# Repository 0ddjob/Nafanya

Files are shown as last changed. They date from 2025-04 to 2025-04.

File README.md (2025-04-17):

# Нафаня (Nafanya) ZX Spectrum Clone
The Нафаня is a late Soviet-era (1991) ZX Spectrum clone out of the Russian SFSR.<br>  
My Нафаня is serial no. 00872.<br>

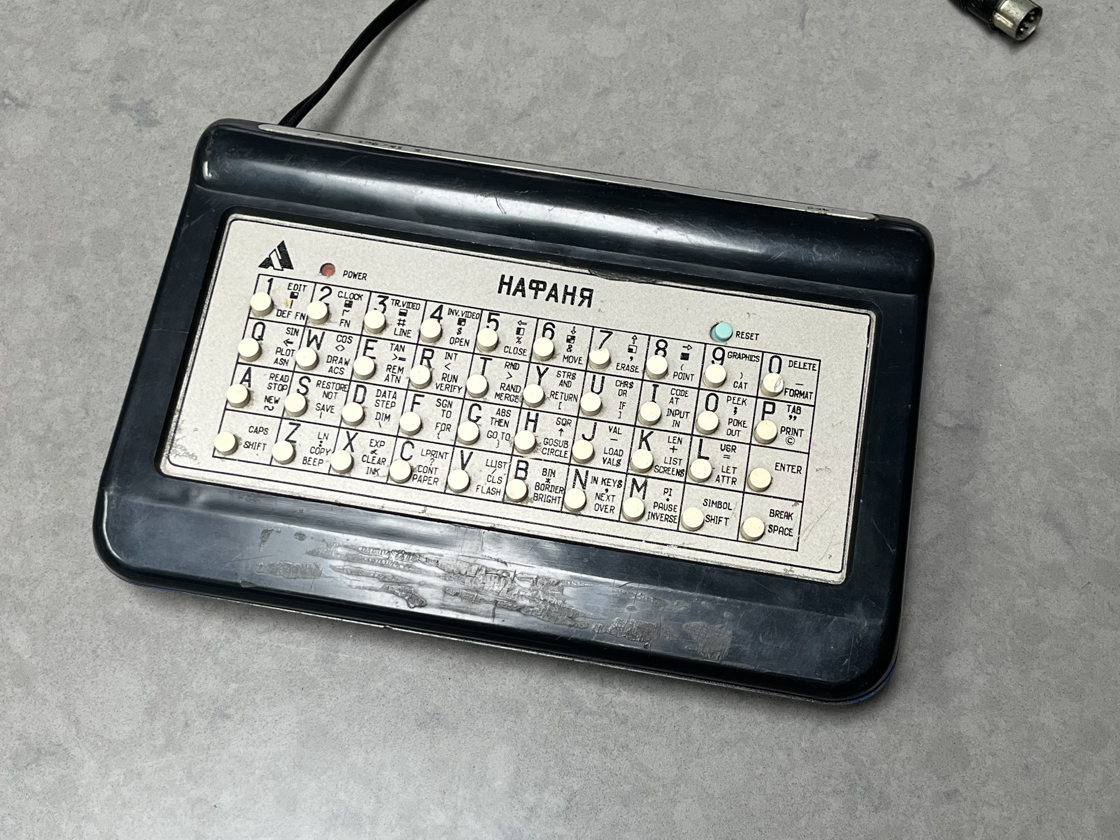
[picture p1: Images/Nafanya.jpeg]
Nafanya


My particular example has a nice, ceramic Z80 from DDR (East Germany) as well as a ceramic БМК (Basic Matrix Crystal, Soviet version of a ULA or Gate Array).<br>

It looked like the original, good quality capacitors were removed from my machine due to their precious-metal content.  They were substituted with poor quality replacements.  I, in turn, replaced them with better quality ones ... this greatly stabilised the RGB video output!  I also added a lot more decoupling capacitors - there was provision for them on the board but they were not installed.<br>

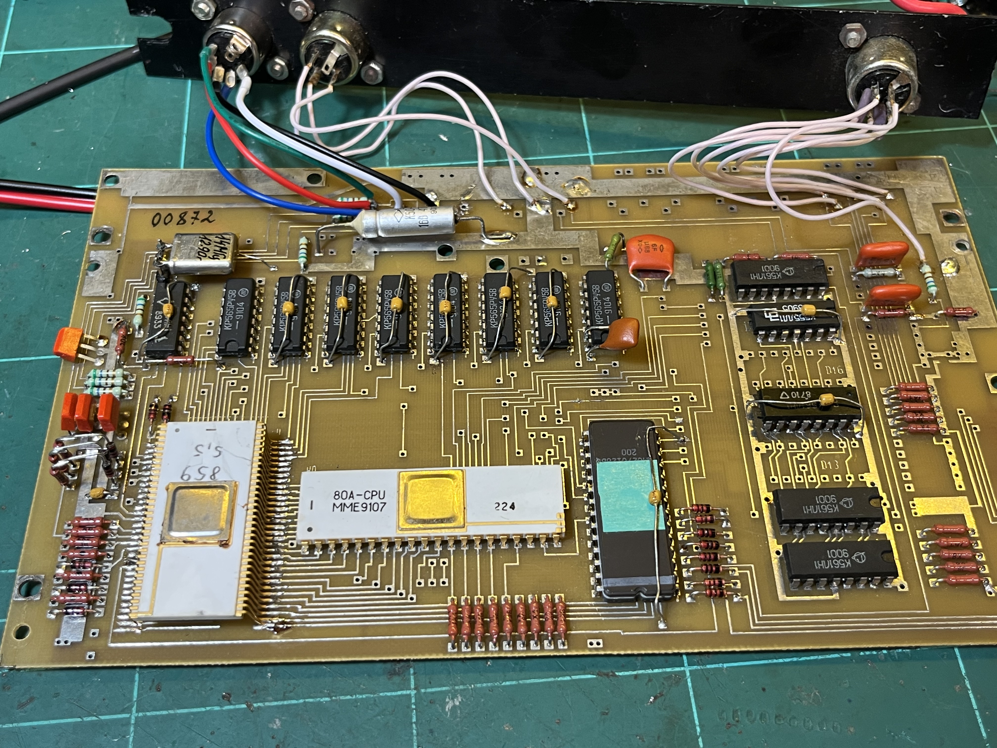
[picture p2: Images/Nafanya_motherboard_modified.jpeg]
Nafanya motherboard


## [Video](https://www.youtube.com/playlist?list=PL5pwokf56wMLiZ0rl97ZL9QdxtgF-uewT)
My YouTube videos:
- [Part 1 (Power On & Troubleshooting)](https://youtu.be/pPQIZv7UhS0)
- [Part 2 (Quick Update)](https://youtu.be/jH4AOVMjng8)
- [Part 3 (Replacement Keyboard Plans)](https://youtu.be/gZ2KwFe9IKs)

## [ROM](/ROM)
The ROM from my machine can be found in this repository.<br>

It has a pretty cool boot screen - I assume this is depicting the character "Нафаня" the computer is named after, a домовой (domovoy, or house spirit) from the Soviet animated film series "Домовёнок Кузя" (Domovyonok Kuzya, or "Kuzya the Little Domovoy") which is based on a children's book by Tatiana Aleksandrova.<br>

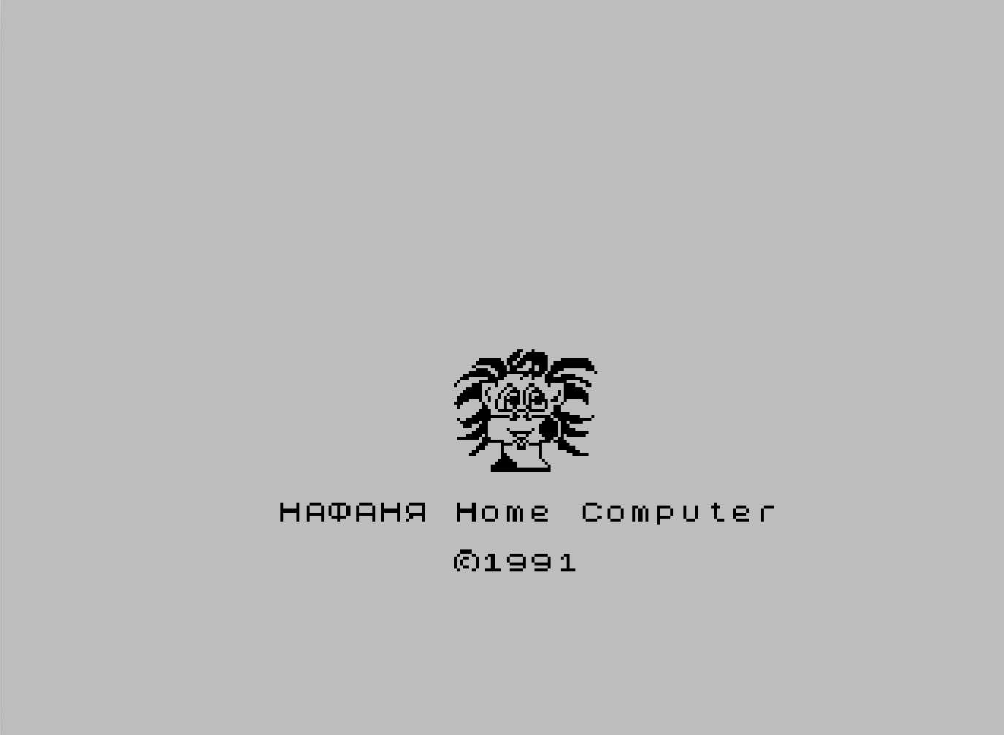
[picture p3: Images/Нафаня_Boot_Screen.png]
Nafanya boot screen


## [New Keyboard](/Nafanya_Keyboard)
The keyboard is not terribly good. Here is a re-designed one using tactile switches that should fit in the existing case.<br>

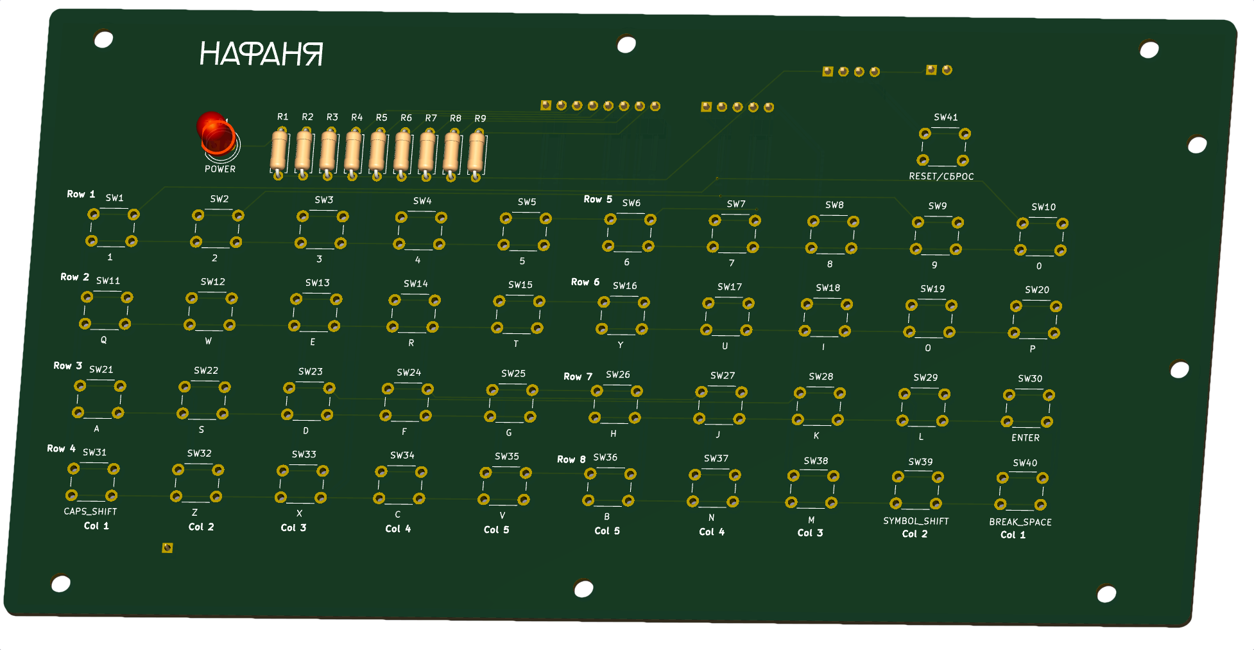
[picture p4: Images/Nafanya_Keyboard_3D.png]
Modern Nafanya Keyboard


### Status
6-Apr-2025:  Still being finalised. The switch positions are slightly off as you go from left to right.
17-Apr-2025: Finalised switch layout, sent for test fabrication.

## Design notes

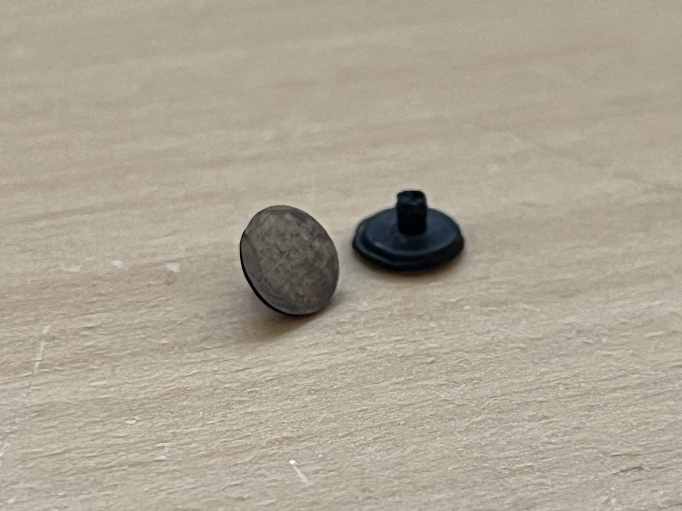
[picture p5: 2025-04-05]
Images/Nafanya_Keyboard_2.jpeg

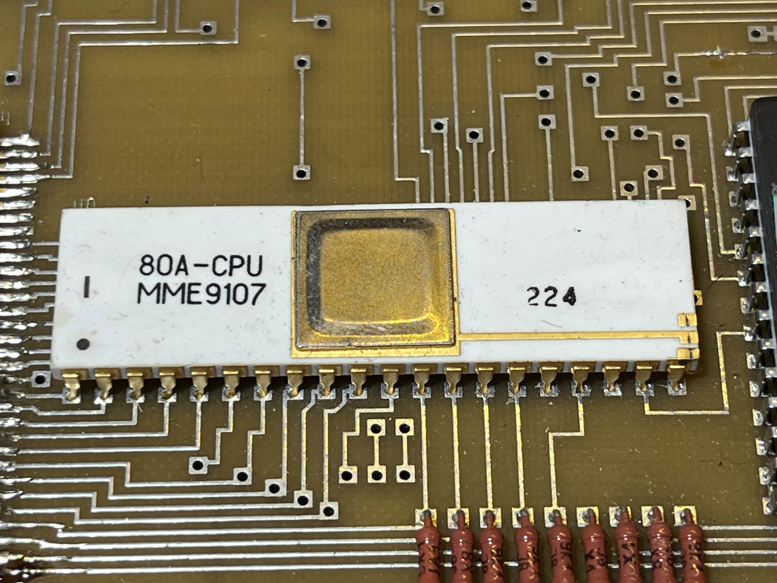
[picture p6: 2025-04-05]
Images/Nafanya_CPU_DDR_Z80.jpeg

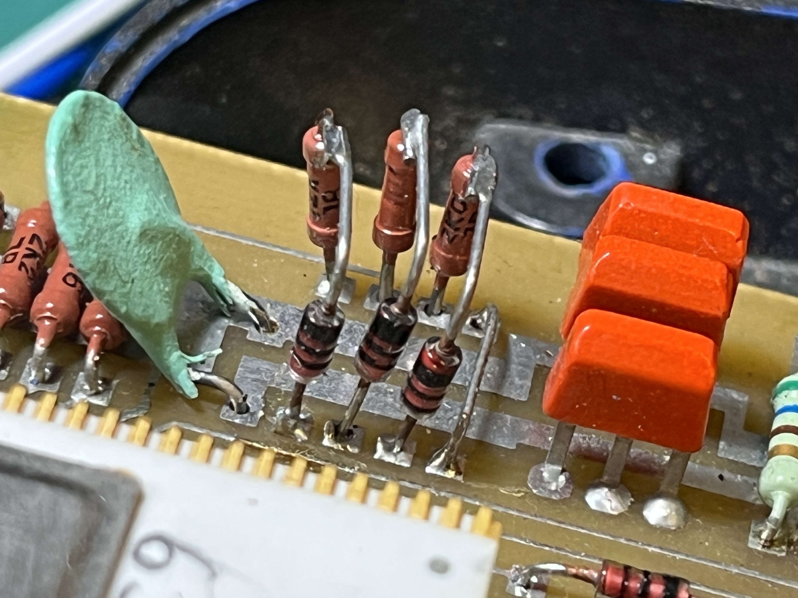
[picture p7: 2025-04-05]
Images/Nafanya_Video_circuit_4.jpeg

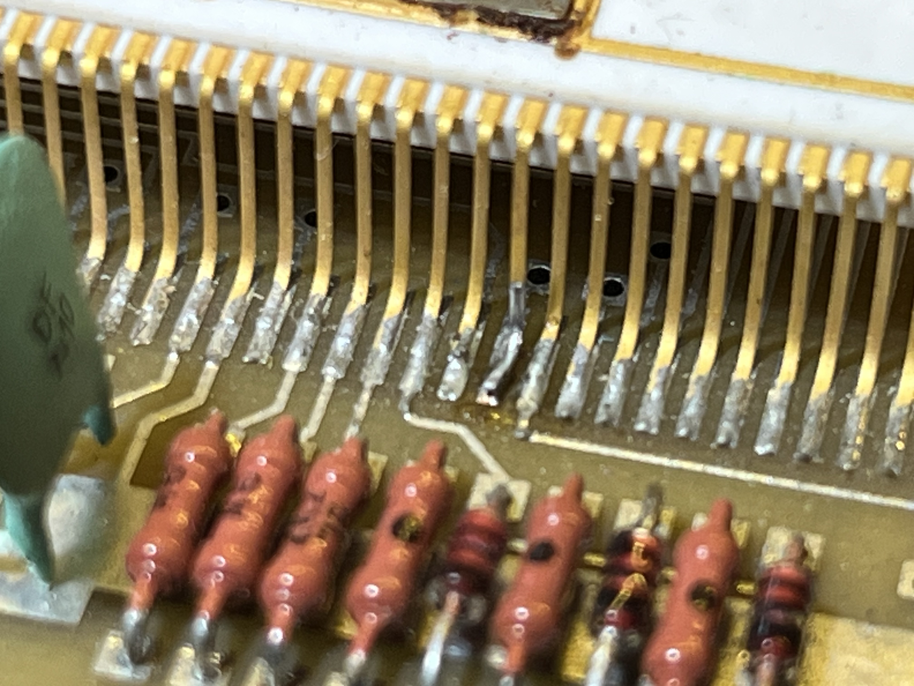
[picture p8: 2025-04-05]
Images/Nafanya_BMC_dodgy_leg.jpeg

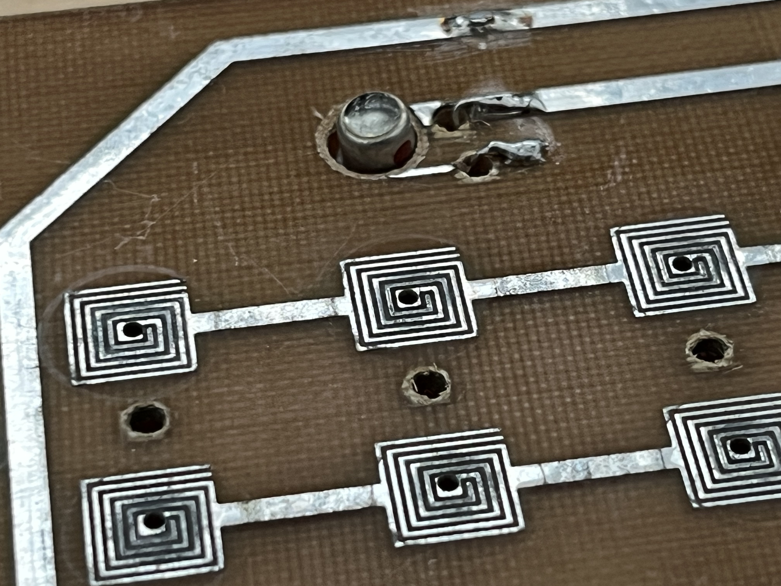
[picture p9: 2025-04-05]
Images/Nafanya_Keyboard_4.jpeg

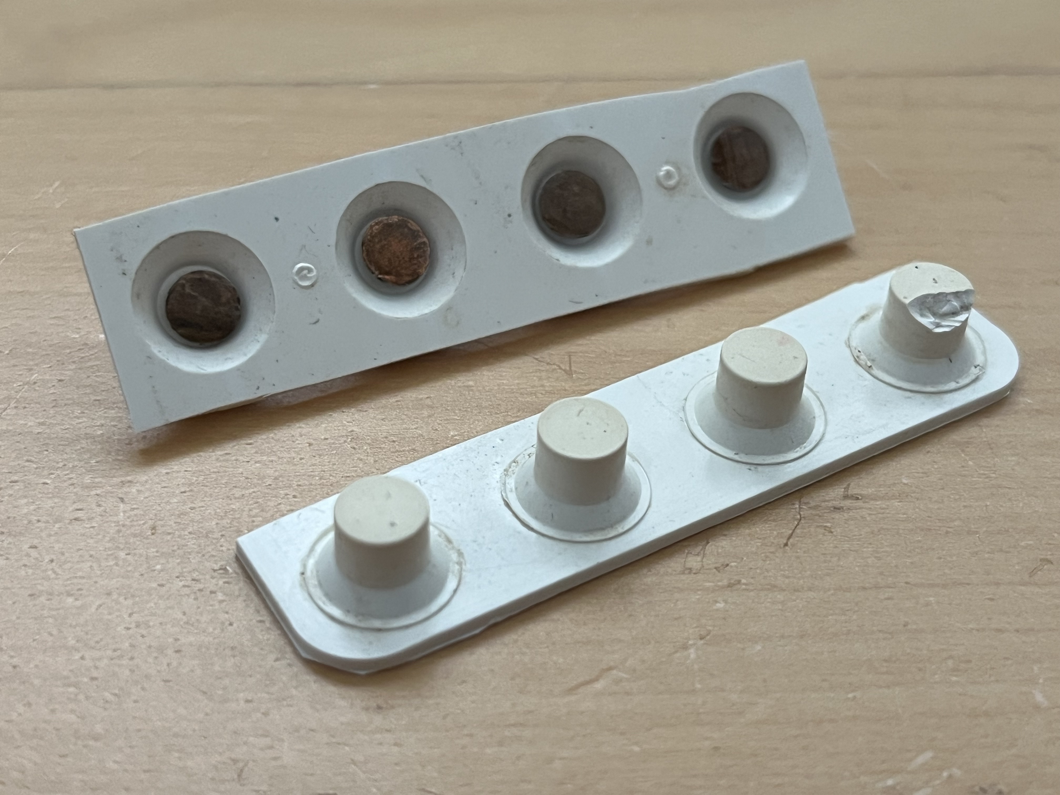
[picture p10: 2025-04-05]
Images/Nafanya_Keyboard_1.jpeg

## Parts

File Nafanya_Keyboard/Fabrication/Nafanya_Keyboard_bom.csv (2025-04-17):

Designator | Quantity | Value | Footprint | Package | MPN | DNP | Mount_Type | Description | Sim.Pins
D1 | 1 | POWER | LED_D5.0mm |  |  |  | tht | Light emitting diode | 1=K 2=A
J1 | 1 | Speaker/Reset/Power | PinHeader_1x04_P2.54mm_Horizontal |  |  |  | tht | Generic connector, single row, 01x04, script generated
J2 | 1 | Columns | PinHeader_1x05_P2.54mm_Horizontal |  |  |  | tht | Generic connector, single row, 01x05, script generated
J3 | 1 | Rows | PinHeader_1x08_P2.54mm_Horizontal |  |  |  | tht | Generic connector, single row, 01x08, script generated
J4 | 1 | Faceplate GND | PinSocket_1x01_P2.54mm_Vertical |  |  |  | tht | Generic connector, single row, 01x01, script generated
LS1 | 1 | Speaker | PinHeader_1x02_P2.54mm_Vertical |  |  |  | tht | Speaker
R1 | 1 | 300Ω | R_Axial_DIN0207_L6.3mm_D2.5mm_P7.62mm_Horizontal |  |  |  | tht | Resistor
R2, R3, R4, R5, R6, R7, R8, R9 | 8 | 10KΩ | R_Axial_DIN0207_L6.3mm_D2.5mm_P7.62mm_Horizontal |  |  |  | tht | Resistor
SW1 | 1 | 1 | SW_PUSH_6mm_H8.5mm |  |  |  | tht | Push button switch, normally open, two pins, 45° tilted
SW10 | 1 | 0 | SW_PUSH_6mm_H8.5mm |  |  |  | tht | Push button switch, normally open, two pins, 45° tilted
SW11 | 1 | Q | SW_PUSH_6mm_H8.5mm |  |  |  | tht | Push button switch, normally open, two pins, 45° tilted
SW12 | 1 | W | SW_PUSH_6mm_H8.5mm |  |  |  | tht | Push button switch, normally open, two pins, 45° tilted
SW13 | 1 | E | SW_PUSH_6mm_H8.5mm |  |  |  | tht | Push button switch, normally open, two pins, 45° tilted
SW14 | 1 | R | SW_PUSH_6mm_H8.5mm |  |  |  | tht | Push button switch, normally open, two pins, 45° tilted
SW15 | 1 | T | SW_PUSH_6mm_H8.5mm |  |  |  | tht | Push button switch, normally open, two pins, 45° tilted
SW16 | 1 | Y | SW_PUSH_6mm_H8.5mm |  |  |  | tht | Push button switch, normally open, two pins, 45° tilted
SW17 | 1 | U | SW_PUSH_6mm_H8.5mm |  |  |  | tht | Push button switch, normally open, two pins, 45° tilted
SW18 | 1 | I | SW_PUSH_6mm_H8.5mm |  |  |  | tht | Push button switch, normally open, two pins, 45° tilted
SW19 | 1 | O | SW_PUSH_6mm_H8.5mm |  |  |  | tht | Push button switch, normally open, two pins, 45° tilted
SW2 | 1 | 2 | SW_PUSH_6mm_H8.5mm |  |  |  | tht | Push button switch, normally open, two pins, 45° tilted
SW20 | 1 | P | SW_PUSH_6mm_H8.5mm |  |  |  | tht | Push button switch, normally open, two pins, 45° tilted
SW21 | 1 | A | SW_PUSH_6mm_H8.5mm |  |  |  | tht | Push button switch, normally open, two pins, 45° tilted
SW22 | 1 | S | SW_PUSH_6mm_H8.5mm |  |  |  | tht | Push button switch, normally open, two pins, 45° tilted
SW23 | 1 | D | SW_PUSH_6mm_H8.5mm |  |  |  | tht | Push button switch, normally open, two pins, 45° tilted
SW24 | 1 | F | SW_PUSH_6mm_H8.5mm |  |  |  | tht | Push button switch, normally open, two pins, 45° tilted
SW25 | 1 | G | SW_PUSH_6mm_H8.5mm |  |  |  | tht | Push button switch, normally open, two pins, 45° tilted
SW26 | 1 | H | SW_PUSH_6mm_H8.5mm |  |  |  | tht | Push button switch, normally open, two pins, 45° tilted
SW27 | 1 | J | SW_PUSH_6mm_H8.5mm |  |  |  | tht | Push button switch, normally open, two pins, 45° tilted
SW28 | 1 | K | SW_PUSH_6mm_H8.5mm |  |  |  | tht | Push button switch, normally open, two pins, 45° tilted
SW29 | 1 | L | SW_PUSH_6mm_H8.5mm |  |  |  | tht | Push button switch, normally open, two pins, 45° tilted
SW3 | 1 | 3 | SW_PUSH_6mm_H8.5mm |  |  |  | tht | Push button switch, normally open, two pins, 45° tilted
SW30 | 1 | ENTER | SW_PUSH_6mm_H8.5mm |  |  |  | tht | Push button switch, normally open, two pins, 45° tilted
SW31 | 1 | CAPS_SHIFT | SW_PUSH_6mm_H8.5mm |  |  |  | tht | Push button switch, normally open, two pins, 45° tilted
SW32 | 1 | Z | SW_PUSH_6mm_H8.5mm |  |  |  | tht | Push button switch, normally open, two pins, 45° tilted
SW33 | 1 | X | SW_PUSH_6mm_H8.5mm |  |  |  | tht | Push button switch, normally open, two pins, 45° tilted
SW34 | 1 | C | SW_PUSH_6mm_H8.5mm |  |  |  | tht | Push button switch, normally open, two pins, 45° tilted
SW35 | 1 | V | SW_PUSH_6mm_H8.5mm |  |  |  | tht | Push button switch, normally open, two pins, 45° tilted
SW36 | 1 | B | SW_PUSH_6mm_H8.5mm |  |  |  | tht | Push button switch, normally open, two pins, 45° tilted
SW37 | 1 | N | SW_PUSH_6mm_H8.5mm |  |  |  | tht | Push button switch, normally open, two pins, 45° tilted
SW38 | 1 | M | SW_PUSH_6mm_H8.5mm |  |  |  | tht | Push button switch, normally open, two pins, 45° tilted
SW39 | 1 | SYMBOL_SHIFT | SW_PUSH_6mm_H8.5mm |  |  |  | tht | Push button switch, normally open, two pins, 45° tilted
SW4 | 1 | 4 | SW_PUSH_6mm_H8.5mm |  |  |  | tht | Push button switch, normally open, two pins, 45° tilted
SW40 | 1 | BREAK_SPACE | SW_PUSH_6mm_H8.5mm |  |  |  | tht | Push button switch, normally open, two pins, 45° tilted
SW41 | 1 | RESET/СБРОС | SW_PUSH_6mm_H8.5mm |  |  |  | tht | Push button switch, generic, two pins
SW5 | 1 | 5 | SW_PUSH_6mm_H8.5mm |  |  |  | tht | Push button switch, normally open, two pins, 45° tilted
SW6 | 1 | 6 | SW_PUSH_6mm_H8.5mm |  |  |  | tht | Push button switch, normally open, two pins, 45° tilted
SW7 | 1 | 7 | SW_PUSH_6mm_H8.5mm |  |  |  | tht | Push button switch, normally open, two pins, 45° tilted
SW8 | 1 | 8 | SW_PUSH_6mm_H8.5mm |  |  |  | tht | Push button switch, normally open, two pins, 45° tilted
SW9 | 1 | 9 | SW_PUSH_6mm_H8.5mm |  |  |  | tht | Push button switch, normally open, two pins, 45° tilted

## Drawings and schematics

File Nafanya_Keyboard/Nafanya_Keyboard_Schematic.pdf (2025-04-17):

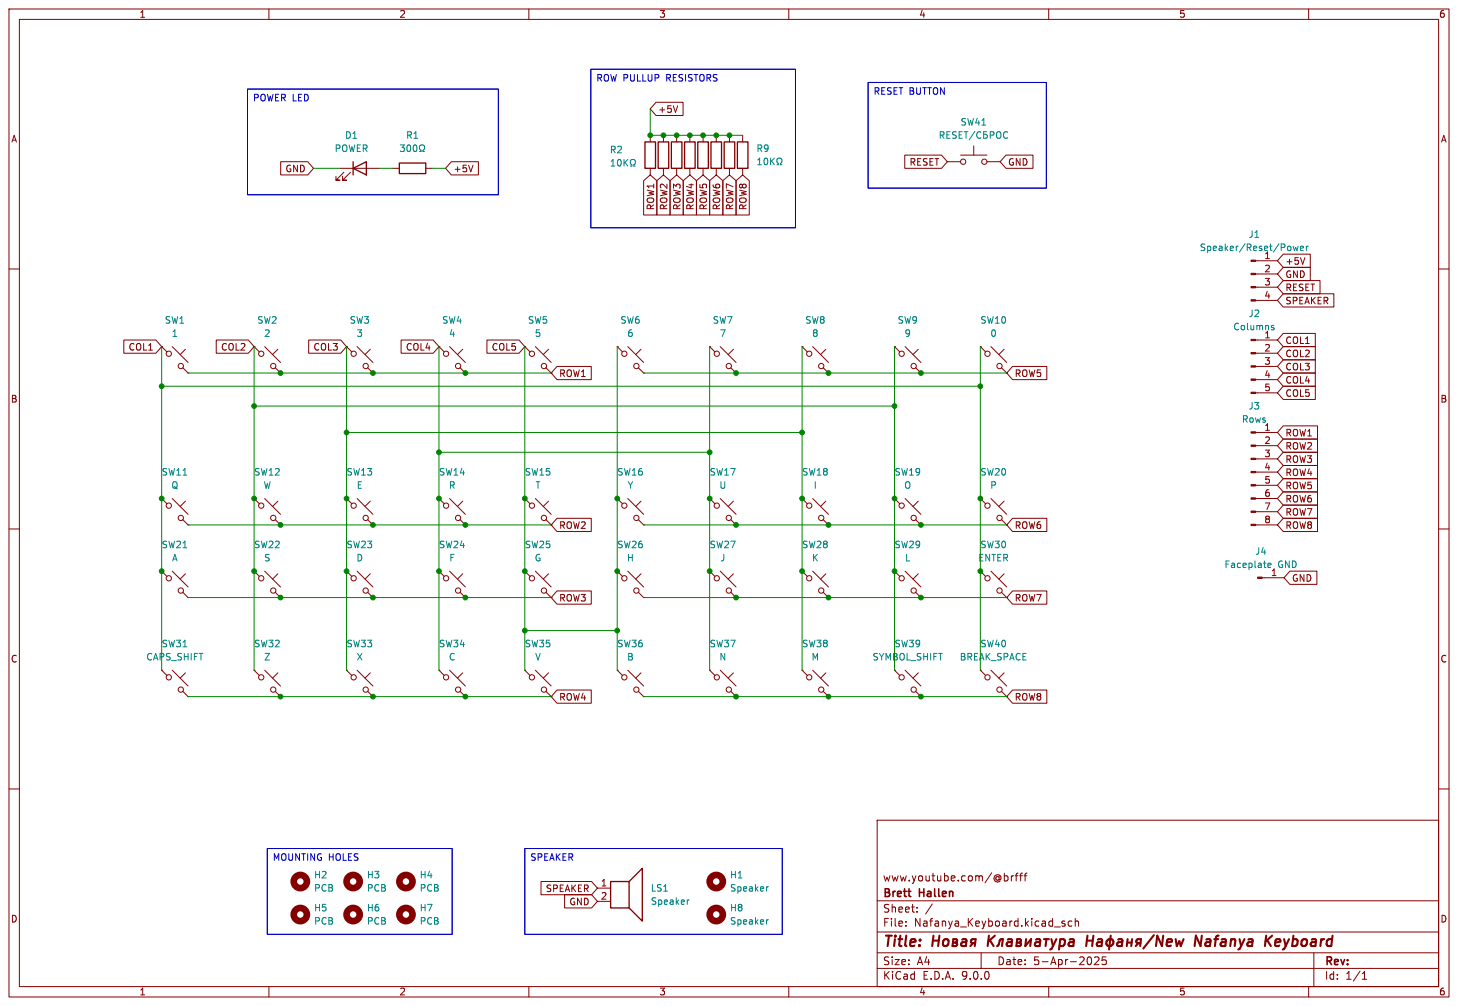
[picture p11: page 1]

RESET BUTTON POWER LED

Id: 1/1 Title: þÿ>20Oþÿ;0280BC@0 þÿ0D0=O/New Nafanya Keyboard

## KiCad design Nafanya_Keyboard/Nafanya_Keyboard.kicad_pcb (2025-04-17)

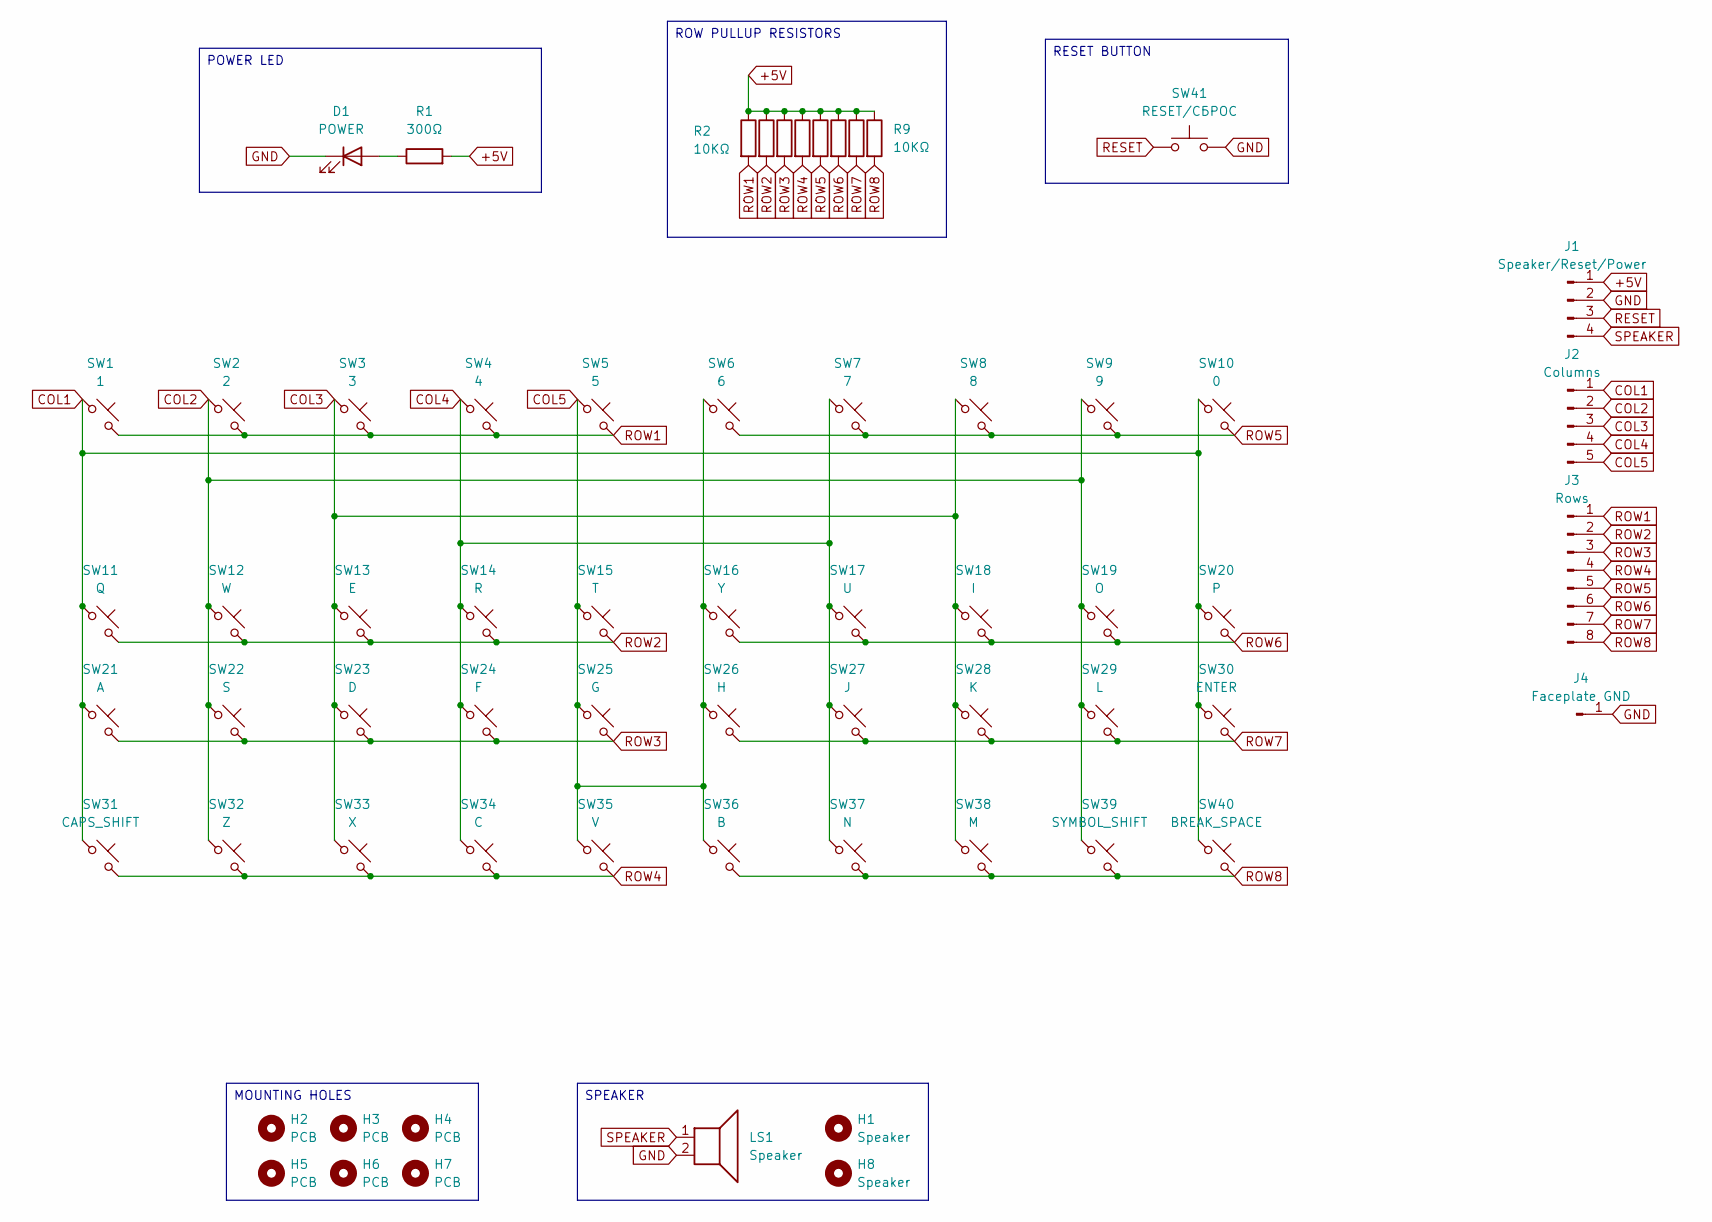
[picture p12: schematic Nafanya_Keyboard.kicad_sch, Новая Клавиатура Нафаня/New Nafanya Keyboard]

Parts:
D1: POWER; LED_D5.0mm
H1, H8: Speaker; MountingHole_3.2mm_M3
H2, H3, H4, H5, H6, H7: PCB; MountingHole_3.2mm_M3
J1: Speaker/Reset/Power; PinHeader_1x04_P2.54mm_Horizontal
J2: Columns; PinHeader_1x05_P2.54mm_Horizontal
J3: Rows; PinHeader_1x08_P2.54mm_Horizontal
J4: Faceplate GND; PinSocket_1x01_P2.54mm_Vertical
LS1: Speaker; PinHeader_1x02_P2.54mm_Vertical
R1: 300Ω; R_Axial_DIN0207_L6.3mm_D2.5mm_P7.62mm_Horizontal
R2, R3, R4, R5, R6, R7, R8, R9: 10KΩ; R_Axial_DIN0207_L6.3mm_D2.5mm_P7.62mm_Horizontal
SW1: 1; SW_PUSH_6mm
SW2: 2; SW_PUSH_6mm
SW3: 3; SW_PUSH_6mm
SW4: 4; SW_PUSH_6mm
SW5: 5; SW_PUSH_6mm
SW6: 6; SW_PUSH_6mm
SW7: 7; SW_PUSH_6mm
SW8: 8; SW_PUSH_6mm
SW9: 9; SW_PUSH_6mm
SW10: 0; SW_PUSH_6mm
SW11: Q; SW_PUSH_6mm
SW12: W; SW_PUSH_6mm
SW13: E; SW_PUSH_6mm
SW14: R; SW_PUSH_6mm
SW15: T; SW_PUSH_6mm
SW16: Y; SW_PUSH_6mm
SW17: U; SW_PUSH_6mm
SW18: I; SW_PUSH_6mm
SW19: O; SW_PUSH_6mm
SW20: P; SW_PUSH_6mm
SW21: A; SW_PUSH_6mm
SW22: S; SW_PUSH_6mm
SW23: D; SW_PUSH_6mm
SW24: F; SW_PUSH_6mm
SW25: G; SW_PUSH_6mm
SW26: H; SW_PUSH_6mm
SW27: J; SW_PUSH_6mm
SW28: K; SW_PUSH_6mm
SW29: L; SW_PUSH_6mm
SW30: ENTER; SW_PUSH_6mm
SW31: CAPS_SHIFT; SW_PUSH_6mm
SW32: Z; SW_PUSH_6mm
SW33: X; SW_PUSH_6mm
SW34: C; SW_PUSH_6mm
SW35: V; SW_PUSH_6mm
SW36: B; SW_PUSH_6mm
SW37: N; SW_PUSH_6mm
SW38: M; SW_PUSH_6mm
SW39: SYMBOL_SHIFT; SW_PUSH_6mm
SW40: BREAK_SPACE; SW_PUSH_6mm
SW41: RESET/СБРОС; SW_PUSH_6mm

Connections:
+5V: J1.1, R1.2, R2.1, R3.1, R4.1, R5.1, R6.1, R7.1, R8.1, R9.1
COL1: J2.1, SW1.1, SW10.1, SW11.1, SW20.1, SW21.1, SW30.1, SW31.1, SW40.1
COL2: J2.2, SW2.1, SW9.1, SW12.1, SW19.1, SW22.1, SW29.1, SW32.1, SW39.1
COL3: J2.3, SW3.1, SW8.1, SW13.1, SW18.1, SW23.1, SW28.1, SW33.1, SW38.1
COL4: J2.4, SW4.1, SW7.1, SW14.1, SW17.1, SW24.1, SW27.1, SW34.1, SW37.1
COL5: J2.5, SW5.1, SW6.1, SW15.1, SW16.1, SW25.1, SW26.1, SW35.1, SW36.1
GND: D1.1 (K), J1.2, J4.1, LS1.2, SW41.2
unnamed: D1.2 (A), R1.1
RESET: J1.3, SW41.1
ROW1: J3.1, R2.2, SW1.2, SW2.2, SW3.2, SW4.2, SW5.2
ROW2: J3.2, R3.2, SW11.2, SW12.2, SW13.2, SW14.2, SW15.2
ROW3: J3.3, R4.2, SW21.2, SW22.2, SW23.2, SW24.2, SW25.2
ROW4: J3.4, R5.2, SW31.2, SW32.2, SW33.2, SW34.2, SW35.2
ROW5: J3.5, R6.2, SW6.2, SW7.2, SW8.2, SW9.2, SW10.2
ROW6: J3.6, R7.2, SW16.2, SW17.2, SW18.2, SW19.2, SW20.2
ROW7: J3.7, R8.2, SW26.2, SW27.2, SW28.2, SW29.2, SW30.2
ROW8: J3.8, R9.2, SW36.2, SW37.2, SW38.2, SW39.2, SW40.2
SPEAKER: J1.4, LS1.1

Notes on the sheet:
RESET BUTTON
MOUNTING HOLES
POWER LED
SPEAKER
ROW PULLUP RESISTORS

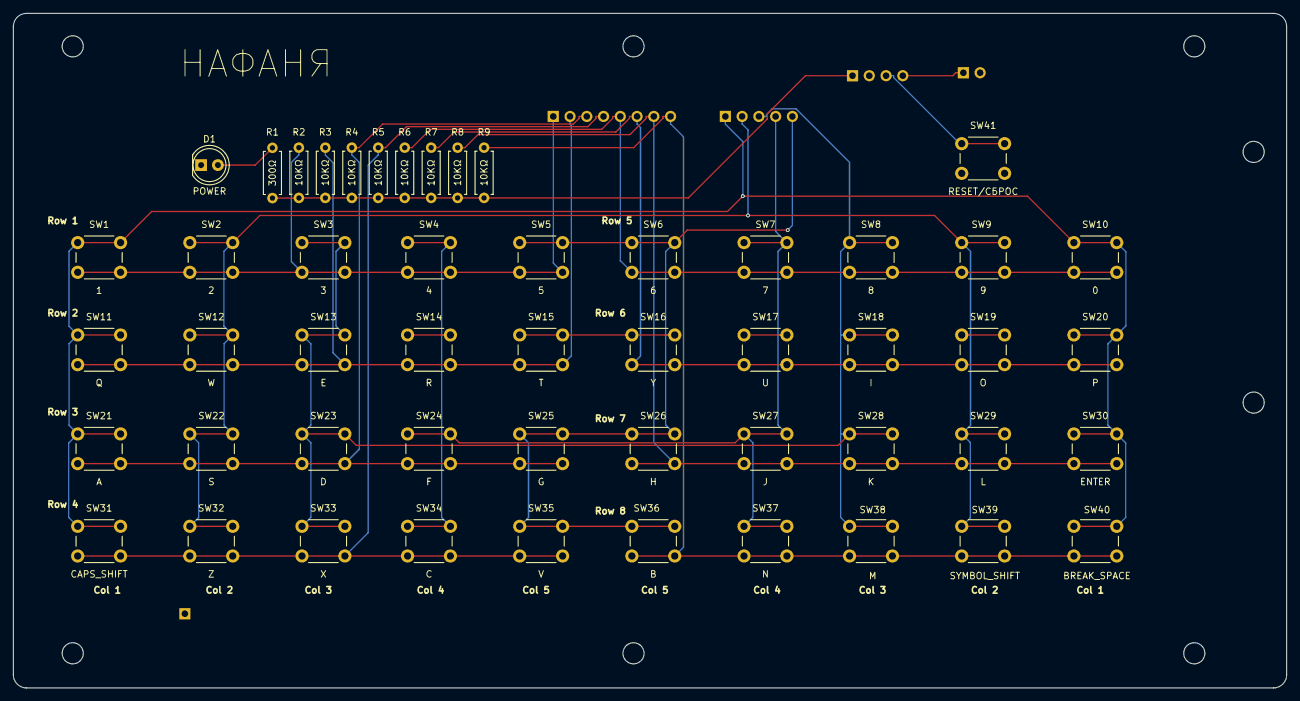
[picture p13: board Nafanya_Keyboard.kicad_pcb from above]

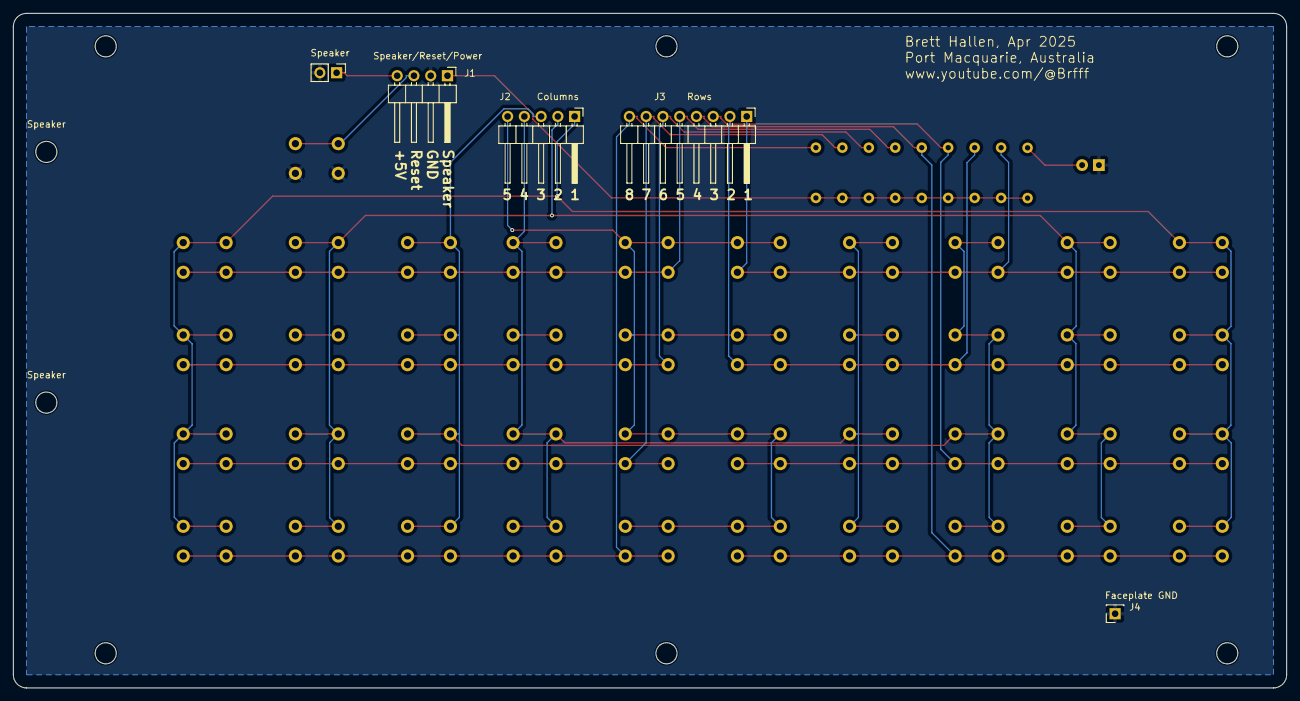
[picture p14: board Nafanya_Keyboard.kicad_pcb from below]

Board: 2 copper layers, 193.0 x 102.2 mm, 64 parts (7 on the bottom side), 18 nets.

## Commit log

2025-04-05 Adding mounting holes
    [Nafanya_Keyboard.kicad_sch]
2025-04-05 PCB started
    [Nafanya_Keyboard.kicad_pcb, Nafanya_Keyboard.kicad_sch]
2025-04-06 Initial keyboard PCB designed
    [Nafanya_Keyboard.kicad_pcb, Nafanya_Keyboard.kicad_sch]
2025-04-06 Refining PCB layout
    [Nafanya_Keyboard.kicad_pcb]
2025-04-07 Added СХЕМА ПОДКЛЮЧЕНИЯ КОМПЬЮТЕРА
2025-04-17 Finalised layout
    [Nafanya_Keyboard.kicad_pcb, Nafanya_Keyboard.kicad_sch, Nafanya_Keyboard_bom.csv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]
2025-04-17 Updated 3D PCB view
2025-04-17 Generated BOM
